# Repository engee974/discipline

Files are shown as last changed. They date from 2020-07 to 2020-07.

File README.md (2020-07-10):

# DISCIPLINE V2

**65% keyboard assembled with only through hole components, including usb type-c**

**[LICENSE](LICENSE)**

Discipline V2 is licensed under the [Creative Commons Attribution-NonCommercial 4.0 International License](https://creativecommons.org/licenses/by-nc/4.0/). 

This PCB design may be freely reproduced, modified, and manufactured for **PERSONAL USE ONLY** and may not be reproduced in physical form for public sale outside of [CFTKB.com](https://www.cftkb.com). 

If you have built upon this work and have changed the design in a significant way, the non-commercial clause can be waived. If you have developed your own design using files in this repository and would like to sell it, please contact me at bryan@cftkb.com. I fully support those looking to make new things and be creative and will more than likely approve and support your project.

**[BOM, Build Guide, and Flashing Information](./doc)**

**Kits available at [cftkb.com](https://www.cftkb.com)**

**[Optional High Profile Lasercut Acrylic Case](./case)**

discipline
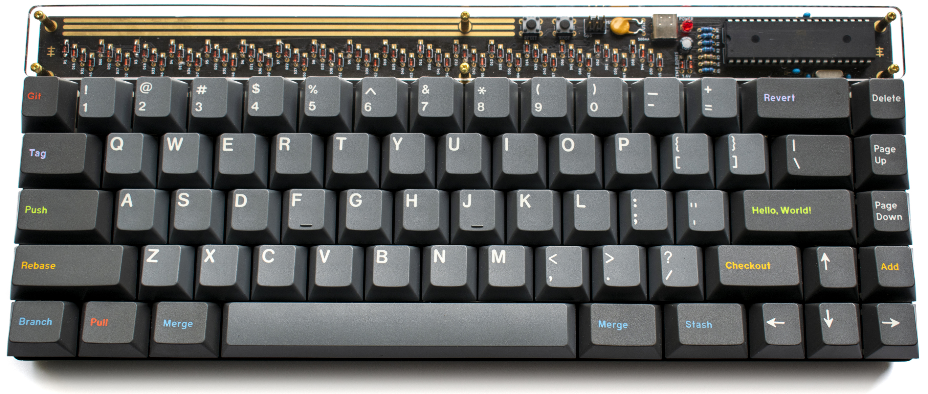
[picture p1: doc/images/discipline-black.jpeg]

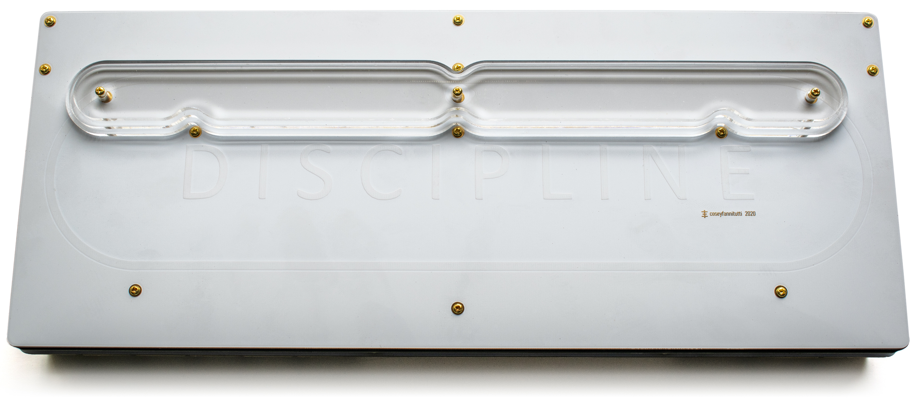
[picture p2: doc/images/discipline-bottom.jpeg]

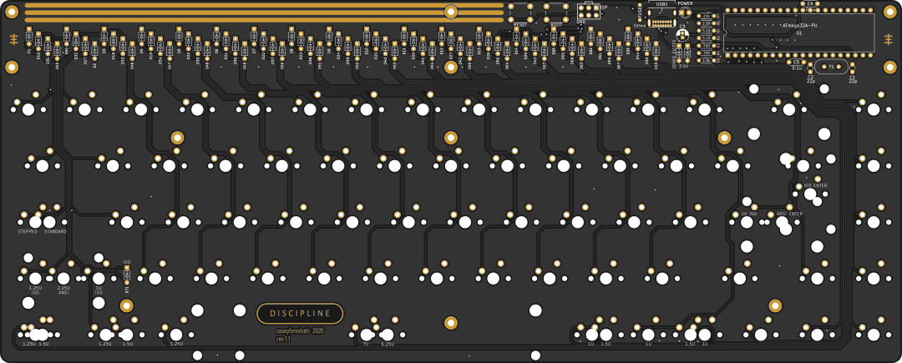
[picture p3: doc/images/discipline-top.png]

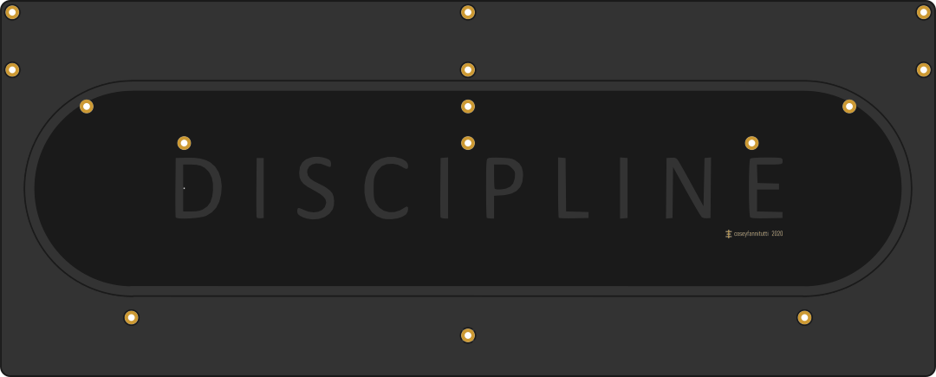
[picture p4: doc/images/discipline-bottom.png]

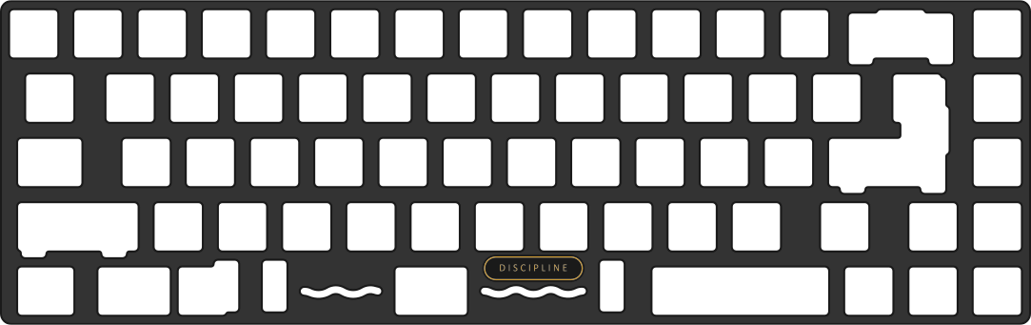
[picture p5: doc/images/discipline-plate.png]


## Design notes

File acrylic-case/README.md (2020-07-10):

# Lasercut Acrylic Case with POM Plate

***This is case is OPTIONAL and not required. The kit has everything you need for a fully functional keyboard.
This case uses a different plate and is NOT compatible with the plate included in the kit.
If you have already soldered switches, you will need to desolder them and swap the plate.***

***I recommend using [Ponoko](https://www.ponoko.com) to cut the pieces. They have all of the correct/required thicknesses and materials in stock and have the best pricing that I have found for multiple one-off parts. Use clear acrylic for the full range of thickness options and Delrin (POM) for the plate. For proper fit please ensure you use the correct dimensions and material thicknesses noted below. Other colors may be used, but of the colors may have limited thickness options, so you may have to narrow material results by thickness to see which colors are available for that size.***

***Ponoko's automatic size detection when uploading is not flawless, so be sure to manually enter the dimensions below.***

## Part Dimensions/Thickness (Top to Bottom)
1. discipline-top-1.dxf - 320.9 x 138.8 mm - ***2mm thickness CLEAR ACRYLIC***
2. discipline-top-2.dxf ***x2 needed*** - 320.9 x 138.8 mm - ***3mm***
3. discipline-plate.dxf - 320.9 x 138.8 mm - ***1.5mm thickness DELRIN(POM)*** Can be black or white.
4. discipline-open-layer.dxf - 320.9 x 138.8 mm - ***4.5mm thickness***
5. discipline-closed-layer.dxf - 320.9 x 138.8 mm - ***3mm thickness***
6. discipline-bottom.dxf - 320.9 x 138.8 - ***3mm thickness*** Use matte (frosted) or colored acrylic if you don't want to clean up the flux on the bottom of your PCB.
7. discipline-foot-1.dxf - 276.5 x 28mm - ***3mm thickness***
8. discipline-foot-2.dxf - 272.5 x 24mm - ***3mm thickness***
9. discipline-foot-3.dxf - 268.5 x 20mm - ***3mm thickness***

## Screws and Standoffs
1. [30x m2x5mm screws](https://www.aliexpress.com/item/32870342767.html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,searchweb201602_7,searchweb201603_53)
2. [12x m2x14mm standoffs](https://www.aliexpress.com/item/32968906213.html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,searchweb201602_7,searchweb201603_53)
3. [3x m2x5mm standoffs](https://www.aliexpress.com/item/32968906213.html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,searchweb201602_7,searchweb201603_53)



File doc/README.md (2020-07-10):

# DISCIPLINE

discipline

[Build Guide](https://static1.squarespace.com/static/5c533d33348cd92b886e544d/t/5e9fbf9e58f1fb0b01f71a7c/1587527585202/DISCIPLINE+BUILD+GUIDE.pdf)

[VIA Configurator Guide (Easiest)](https://static1.squarespace.com/static/5c533d33348cd92b886e544d/t/5e9fd1d198a4166c9ccc5b68/1587532241535/DISCIPLINE+VIA+GUIDE.pdf)

[QMK Toolbox Flashing Guide (not needed if using VIA)](https://static1.squarespace.com/static/5c533d33348cd92b886e544d/t/5e9fd3311e3c4e5bc9f8eb21/1587532594225/DISCIPLINE+FLASHING+GUIDE.pdf)

[Command Line Flashing Guide (Advanced)](https://static1.squarespace.com/static/5c533d33348cd92b886e544d/t/5e9fd3567e131c476b0a4f7e/1587532631133/DISCIPLINE+FLASHING+GUIDE+-+COMMAND+LINE.pdf)

[Bootloader](./bootloader)

[BOM (Parts List)](https://octopart.com/bom-tool/W4rybyut)

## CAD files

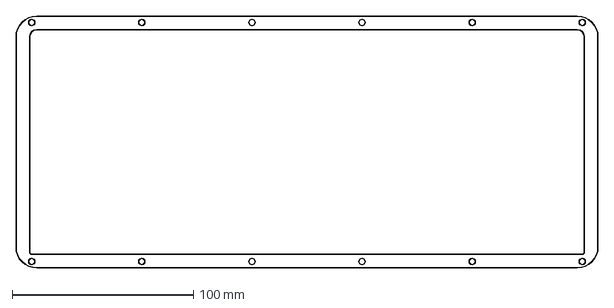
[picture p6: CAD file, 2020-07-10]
acrylic-case/discipline-top2.dxf
320.9 x 138.8 mm

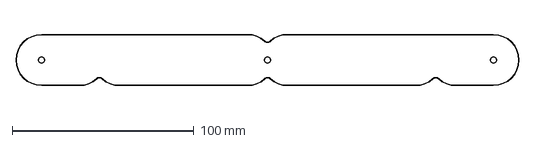
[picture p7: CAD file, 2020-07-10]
kit-acrylic/discipline-kitfoot-1.dxf
276.5 x 28.0 mm

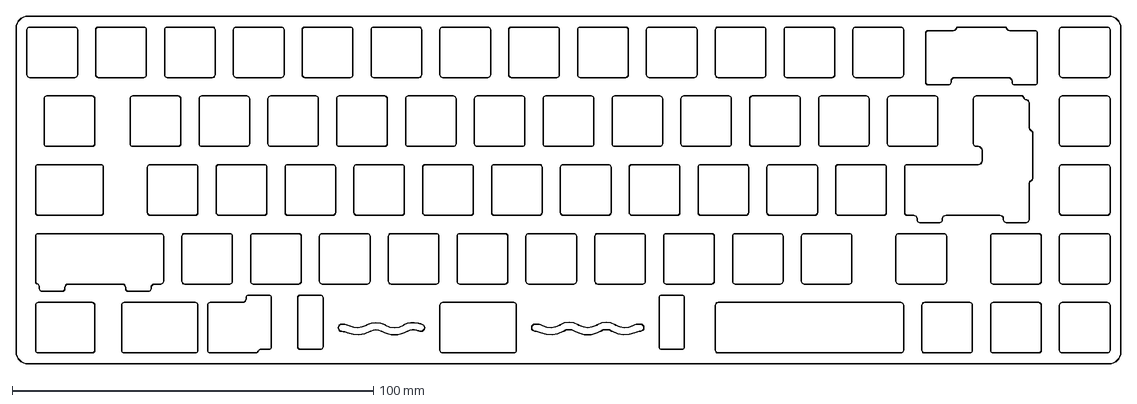
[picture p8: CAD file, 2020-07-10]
plate/discipline-plate-lasercutting.dxf
305.8 x 96.2 mm

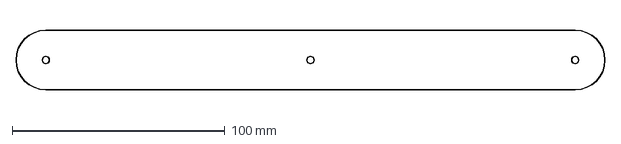
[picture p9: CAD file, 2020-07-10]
acrylic-case/discipline-foot-1.dxf
276.5 x 28.0 mm

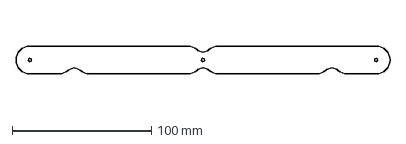
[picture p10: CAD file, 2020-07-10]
kit-acrylic/discipline-kitfoot-3.dxf
268.5 x 20.0 mm

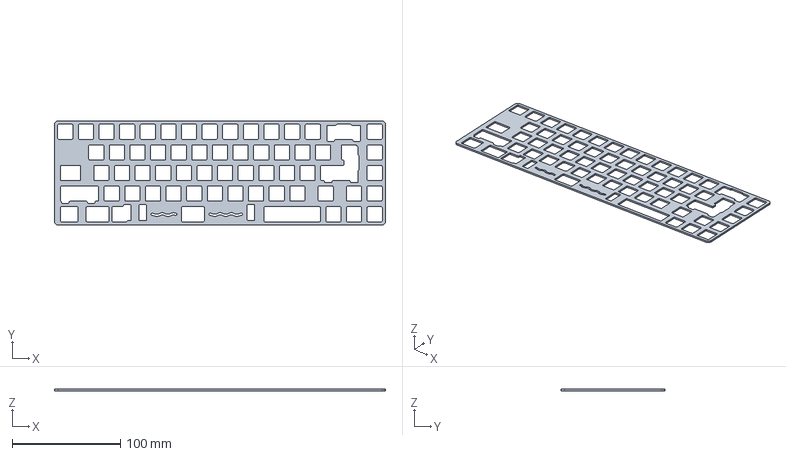
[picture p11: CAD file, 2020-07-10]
plate/discipline-pcb.step
305.8 x 96.2 x 1.60 mm

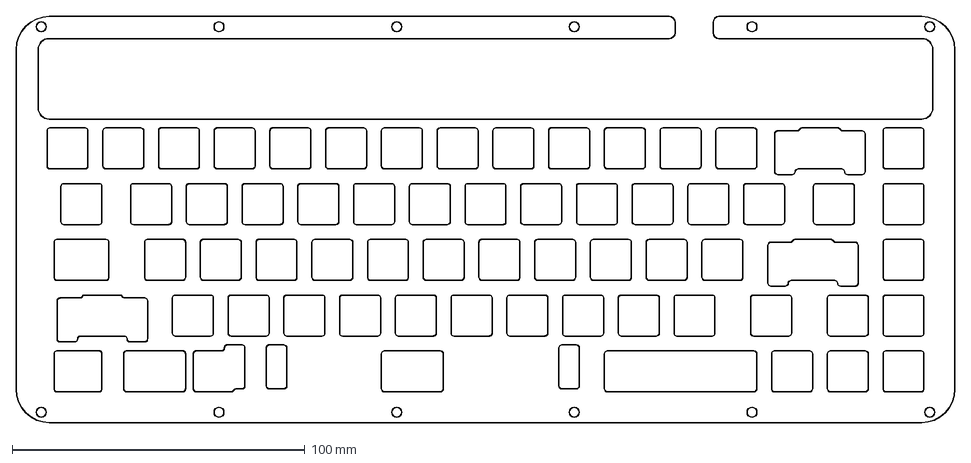
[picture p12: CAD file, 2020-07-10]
acrylic-case/discipline-plate.dxf
320.9 x 138.8 mm

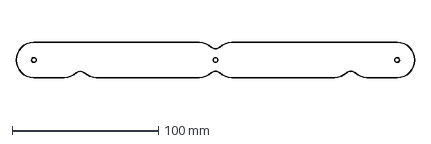
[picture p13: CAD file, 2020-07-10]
kit-acrylic/discipline-kitfoot-2.dxf
272.5 x 24.0 mm

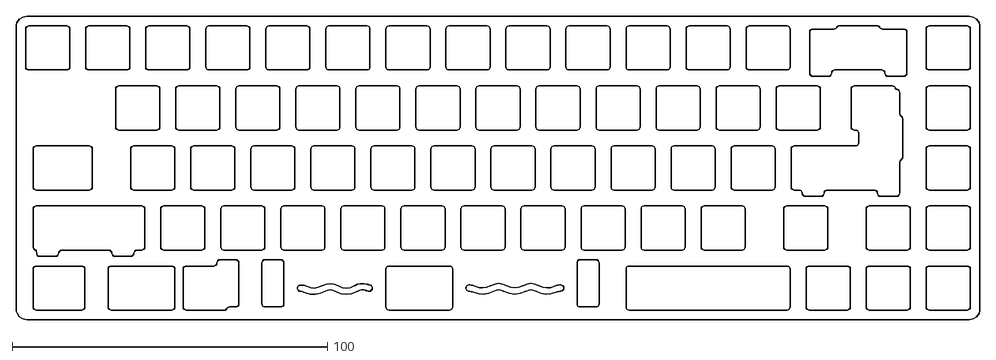
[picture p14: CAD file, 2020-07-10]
plate/discipline-plate-test.dxf
305.8 x 96.2

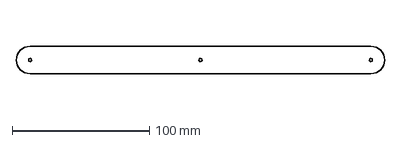
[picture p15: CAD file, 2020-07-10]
acrylic-case/discipline-foot-3.dxf
268.5 x 20.0 mm

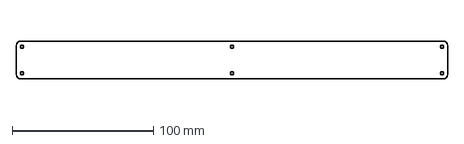
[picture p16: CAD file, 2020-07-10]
kit-acrylic/acrylic-guard.dxf
304.9 x 26.8 mm

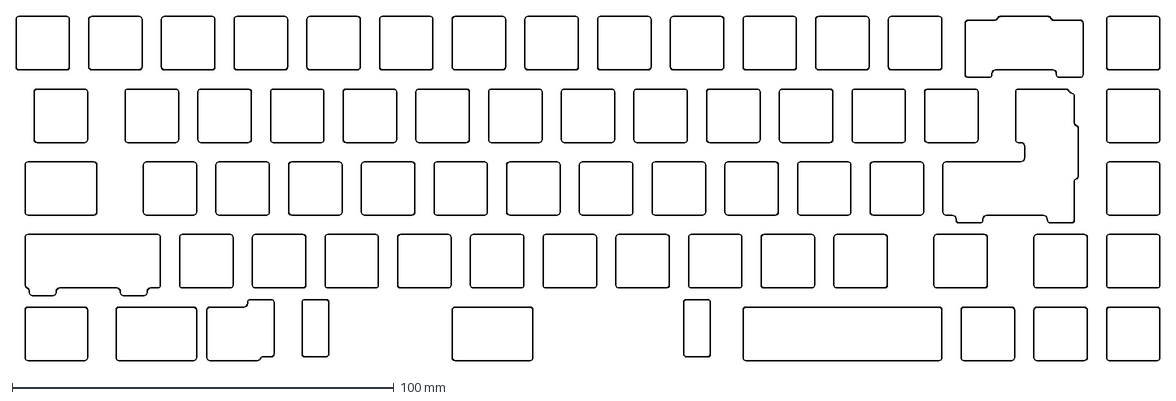
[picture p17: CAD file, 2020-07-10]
plate/discipline-plate-base.dxf
299.8 x 90.2 mm

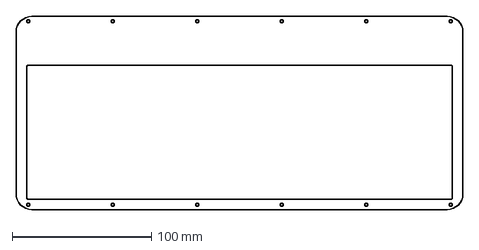
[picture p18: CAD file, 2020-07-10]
acrylic-case/discipline-top1.dxf
320.9 x 138.8 mm

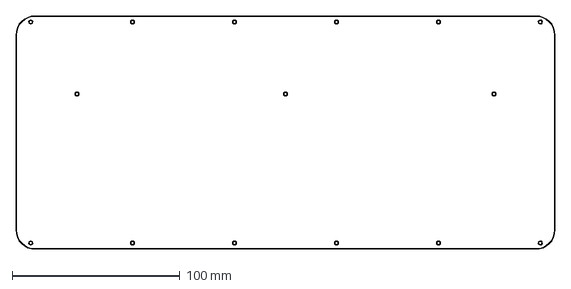
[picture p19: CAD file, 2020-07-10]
acrylic-case/discipline-bottom.dxf
320.9 x 138.8 mm

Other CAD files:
acrylic-case/discipline-open-layer.dxf
acrylic-case/discipline-closed-layer.dxf
acrylic-case/discipline-foot-2.dxf

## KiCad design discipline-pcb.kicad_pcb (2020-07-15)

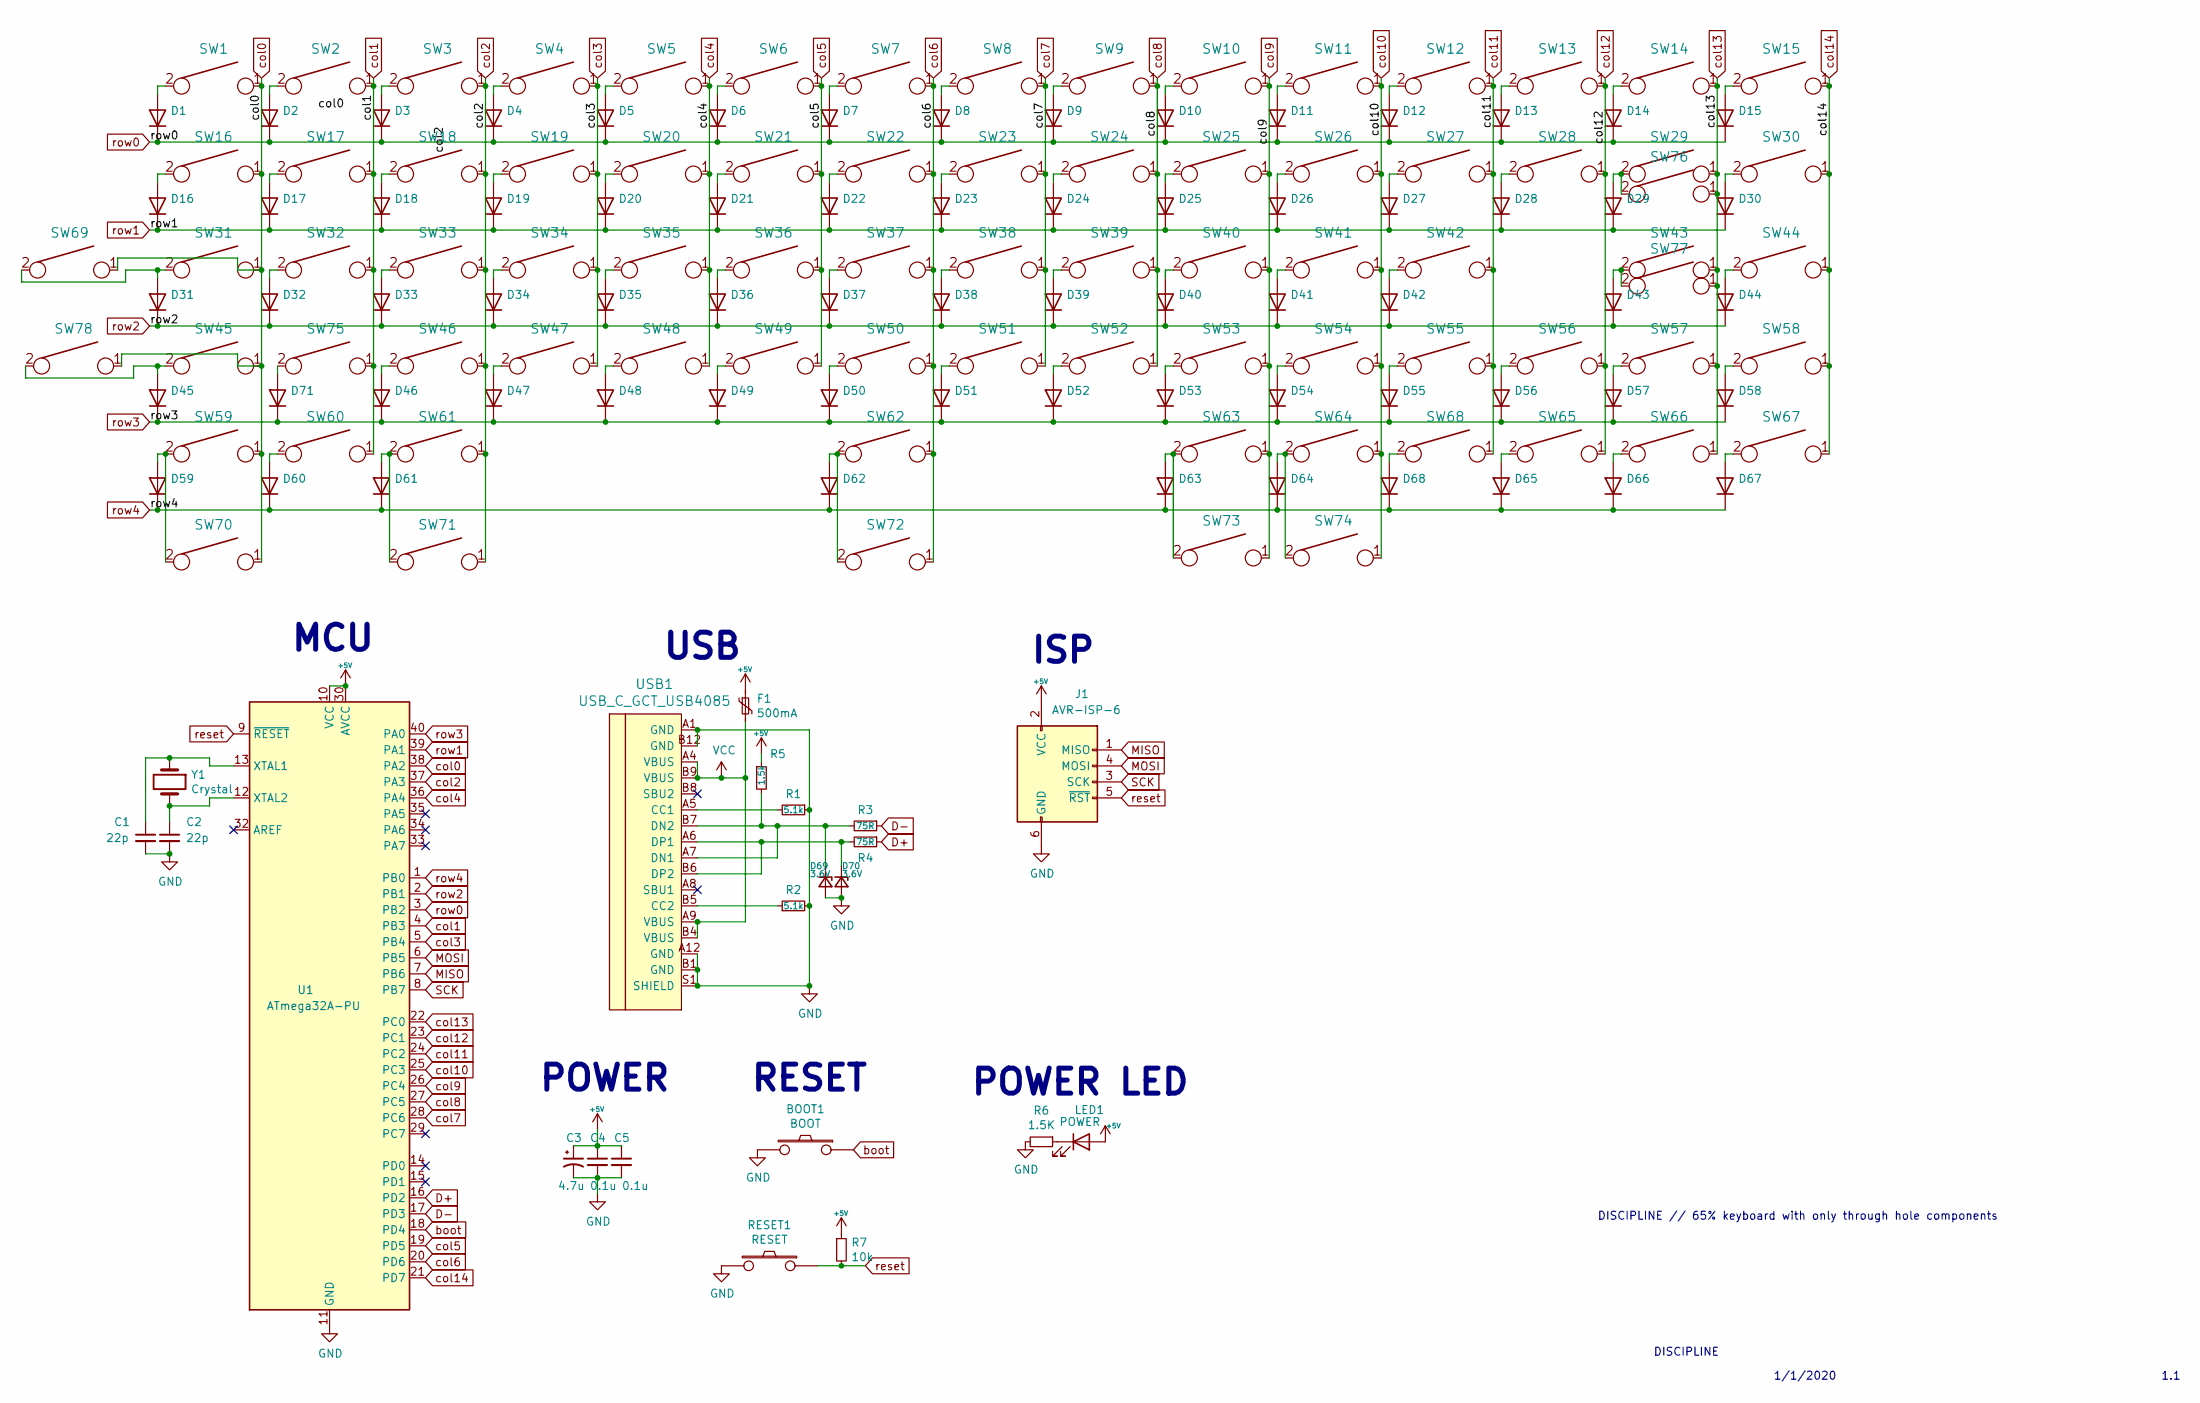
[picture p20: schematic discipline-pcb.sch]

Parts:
BOOT1: BOOT; SW_PUSH_6mm
C1, C2: 22p; C_Disc_D3.0mm_W1.6mm_P2.50mm
C3: 4.7u; CP_Radial_D4.0mm_P1.50mm
C4, C5: 0.1u; C_Disc_D4.3mm_W1.9mm_P5.00mm
D1, D2, D3, D4, D5, D6, D7, D8, D9, D10, D11, D12, D13, D14, D15, D16, D17, D18, D19, D20, D21, D22, D23, D24, D25, D26, D27, D28, D29, D30, D31, D32, D33, D34, D35, D36, D37, D38, D39, D40, D41, D42, D43, D44, D45, D46, D47, D48, D49, D50, D51, D52, D53, D54, D55, D56, D57, D58, D59, D60, D61, D62, D63, D64, D65, D66, D67, D68, D71: D_DO-35_SOD27_P5.08mm_Horizontal
D69, D70: 3.6V; D_DO-35_SOD27_P5.08mm_Horizontal
F1: 500mA; polyfuse_5.1mm
J1: AVR-ISP-6; AVR_ICSP_3x2
LED1: POWER; LED_D3.0mm
R1, R2: 5.1k; R_Axial_DIN0204_L3.6mm_D1.6mm_P5.08mm_Horizontal
R3, R4: 75R; R_Axial_DIN0204_L3.6mm_D1.6mm_P5.08mm_Horizontal
R5: 1.5k; R_Axial_DIN0204_L3.6mm_D1.6mm_P5.08mm_Horizontal
R6: 1.5K; R_Axial_DIN0204_L3.6mm_D1.6mm_P5.08mm_Horizontal
R7: 10k; R_Axial_DIN0204_L3.6mm_D1.6mm_P5.08mm_Horizontal
RESET1: RESET; SW_PUSH_6mm
SW1, SW2, SW3, SW4, SW5, SW6, SW7, SW8, SW9, SW10, SW11, SW12, SW13, SW15, SW17, SW18, SW19, SW20, SW21, SW22, SW23, SW24, SW25, SW26, SW27, SW28, SW30, SW32, SW33, SW34, SW35, SW36, SW37, SW38, SW39, SW40, SW41, SW42, SW44, SW46, SW47, SW48, SW49, SW50, SW51, SW52, SW53, SW54, SW55, SW57, SW58, SW62, SW65, SW66, SW67, SW68, SW72, SW75, SW77: KEYSW; SW_Cherry_MX1A_1.00u_PCB-NOSCREEN
SW14: KEYSW; SW_Cherry_MX1A_2.00u_PCBNOSCREEN
SW16, SW29, SW70, SW71, SW73, SW74: KEYSW; SW_Cherry_MX1A_1.50u_PCBNOSCREEN
SW31, SW56: KEYSW; SW_Cherry_MX1A_1.75u_PCBNOSCREEN
SW43, SW45: KEYSW; SW_Cherry_MX1A_2.25u_PCBNOSCREEN
SW59, SW60, SW61, SW63, SW64, SW69, SW78: KEYSW; SW_Cherry_MX1A_1.25u_PCBNOSCREEN
SW76: KEYSW; SW_Cherry_MX1A_ISOEnter_PCB_ReversedStabilizer
U1: ATmega32A-PU; DIP-40_W15.24mm
USB1: USB_C_GCT_USB4085
Y1: Crystal; Crystal_HC49-4H_Vertical

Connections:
+5V: C3.1, C4.1, C5.1, F1.1, J1.2 (VCC), LED1.2 (A), R5.1, R7.1, U1.10 (VCC), U1.30 (AVCC)
D+: R4.1, U1.16 (PD2)
D-: R3.1, U1.17 (PD3)
GND: BOOT1.1, C1.2, C2.2, C3.2, C4.2, C5.2, D69.2 (A), D70.2 (A), J1.6 (GND), R1.1, R2.2, R6.2, RESET1.1, U1.11 (GND), U1.31 (GND), USB1.A1 (GND), USB1.A12 (GND), USB1.B1 (GND), USB1.B12 (GND), USB1.S1 (SHIELD)
MISO: J1.1 (MISO), U1.7 (PB6)
MOSI: J1.4 (MOSI), U1.6 (PB5)
unnamed: C1.1, U1.13 (XTAL1), Y1.1
unnamed: C2.1, U1.12 (XTAL2), Y1.2
unnamed: D1.2 (A), SW1.2
unnamed: D2.2 (A), SW2.2
unnamed: D3.2 (A), SW3.2
unnamed: D4.2 (A), SW4.2
unnamed: D5.2 (A), SW5.2
unnamed: D6.2 (A), SW6.2
unnamed: D7.2 (A), SW7.2
unnamed: D8.2 (A), SW8.2
unnamed: D9.2 (A), SW9.2
unnamed: D10.2 (A), SW10.2
unnamed: D11.2 (A), SW11.2
unnamed: D12.2 (A), SW12.2
unnamed: D13.2 (A), SW13.2
unnamed: D14.2 (A), SW14.2
unnamed: D15.2 (A), SW15.2
unnamed: D16.2 (A), SW16.2
unnamed: D17.2 (A), SW17.2
unnamed: D18.2 (A), SW18.2
unnamed: D19.2 (A), SW19.2
unnamed: D20.2 (A), SW20.2
unnamed: D21.2 (A), SW21.2
unnamed: D22.2 (A), SW22.2
unnamed: D23.2 (A), SW23.2
unnamed: D24.2 (A), SW24.2
unnamed: D25.2 (A), SW25.2
unnamed: D26.2 (A), SW26.2
unnamed: D27.2 (A), SW27.2
unnamed: D28.2 (A), SW28.2
unnamed: D29.2 (A), SW29.2, SW76.2
unnamed: D30.2 (A), SW30.2
unnamed: D31.2 (A), SW31.2, SW69.2
unnamed: D32.2 (A), SW32.2
unnamed: D33.2 (A), SW33.2
unnamed: D34.2 (A), SW34.2
unnamed: D35.2 (A), SW35.2
unnamed: D36.2 (A), SW36.2
unnamed: D37.2 (A), SW37.2
unnamed: D38.2 (A), SW38.2
unnamed: D39.2 (A), SW39.2
unnamed: D40.2 (A), SW40.2
unnamed: D41.2 (A), SW41.2
unnamed: D42.2 (A), SW42.2
unnamed: D43.2 (A), SW43.2, SW77.2
unnamed: D44.2 (A), SW44.2
unnamed: D45.2 (A), SW45.2, SW78.2
unnamed: D46.2 (A), SW46.2
unnamed: D47.2 (A), SW47.2
unnamed: D48.2 (A), SW48.2
unnamed: D49.2 (A), SW49.2
unnamed: D50.2 (A), SW50.2
unnamed: D51.2 (A), SW51.2
unnamed: D52.2 (A), SW52.2
unnamed: D53.2 (A), SW53.2
unnamed: D54.2 (A), SW54.2
unnamed: D55.2 (A), SW55.2
unnamed: D56.2 (A), SW56.2
unnamed: D57.2 (A), SW57.2
unnamed: D58.2 (A), SW58.2
unnamed: D59.2 (A), SW59.2, SW70.2
unnamed: D60.2 (A), SW60.2
unnamed: D61.2 (A), SW61.2, SW71.2
unnamed: D62.2 (A), SW62.2, SW72.2
unnamed: D63.2 (A), SW63.2, SW73.2
unnamed: D64.2 (A), SW64.2, SW74.2
unnamed: D65.2 (A), SW65.2
unnamed: D66.2 (A), SW66.2
unnamed: D67.2 (A), SW67.2
unnamed: D68.2 (A), SW68.2
unnamed: D69.1 (K), R3.2, R5.2, USB1.A7 (DN1), USB1.B7 (DN2)
unnamed: D70.1 (K), R4.2, USB1.A6 (DP1), USB1.B6 (DP2)
unnamed: D71.2 (A), SW75.2
unnamed: LED1.1 (K), R6.1
unnamed: R1.2, USB1.A5 (CC1)
unnamed: R2.1, USB1.B5 (CC2)
SCK: J1.3 (SCK), U1.8 (PB7)
VCC: F1.2, USB1.A4 (VBUS), USB1.A9 (VBUS), USB1.B4 (VBUS), USB1.B9 (VBUS)
boot: BOOT1.2, U1.18 (PD4)
col0: SW1.1, SW16.1, SW31.1, SW45.1, SW59.1, SW69.1, SW70.1, SW78.1, U1.38 (PA2)
col1: SW2.1, SW17.1, SW32.1, SW60.1, SW75.1, U1.4 (PB3)
col2: SW3.1, SW18.1, SW33.1, SW46.1, SW61.1, SW71.1, U1.37 (PA3)
col3: SW4.1, SW19.1, SW34.1, SW47.1, U1.5 (PB4)
col4: SW5.1, SW20.1, SW35.1, SW48.1, U1.36 (PA4)
col5: SW6.1, SW21.1, SW36.1, SW49.1, U1.19 (PD5)
col6: SW7.1, SW22.1, SW37.1, SW50.1, SW62.1, SW72.1, U1.20 (PD6)
col7: SW8.1, SW23.1, SW38.1, SW51.1, U1.28 (PC6)
col8: SW9.1, SW24.1, SW39.1, SW52.1, U1.27 (PC5)
col9: SW10.1, SW25.1, SW40.1, SW53.1, SW63.1, SW73.1, U1.26 (PC4)
col10: SW11.1, SW26.1, SW41.1, SW54.1, SW64.1, SW74.1, U1.25 (PC3)
col11: SW12.1, SW27.1, SW42.1, SW55.1, SW68.1, U1.24 (PC2)
col12: SW13.1, SW28.1, SW56.1, SW65.1, U1.23 (PC1)
col13: SW14.1, SW29.1, SW43.1, SW57.1, SW66.1, SW76.1, SW77.1, U1.22 (PC0)
col14: SW15.1, SW30.1, SW44.1, SW58.1, SW67.1, U1.21 (PD7)
reset: J1.5 (~RST), R7.2, RESET1.2, U1.9 (~RESET)
row0: D1.1 (K), D2.1 (K), D3.1 (K), D4.1 (K), D5.1 (K), D6.1 (K), D7.1 (K), D8.1 (K), D9.1 (K), D10.1 (K), D11.1 (K), D12.1 (K), D13.1 (K), D14.1 (K), D15.1 (K), U1.3 (PB2)
row1: D16.1 (K), D17.1 (K), D18.1 (K), D19.1 (K), D20.1 (K), D21.1 (K), D22.1 (K), D23.1 (K), D24.1 (K), D25.1 (K), D26.1 (K), D27.1 (K), D28.1 (K), D29.1 (K), D30.1 (K), U1.39 (PA1)
row2: D31.1 (K), D32.1 (K), D33.1 (K), D34.1 (K), D35.1 (K), D36.1 (K), D37.1 (K), D38.1 (K), D39.1 (K), D40.1 (K), D41.1 (K), D42.1 (K), D43.1 (K), D44.1 (K), U1.2 (PB1)
row3: D45.1 (K), D46.1 (K), D47.1 (K), D48.1 (K), D49.1 (K), D50.1 (K), D51.1 (K), D52.1 (K), D53.1 (K), D54.1 (K), D55.1 (K), D56.1 (K), D57.1 (K), D58.1 (K), D71.1 (K), U1.40 (PA0)
row4: D59.1 (K), D60.1 (K), D61.1 (K), D62.1 (K), D63.1 (K), D64.1 (K), D65.1 (K), D66.1 (K), D67.1 (K), D68.1 (K), U1.1 (PB0)

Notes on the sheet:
DISCIPLINE // 65% keyboard with only through hole components
1/1/2020
DISCIPLINE
1.1
MCU
USB
ISP
POWER
RESET
POWER LED

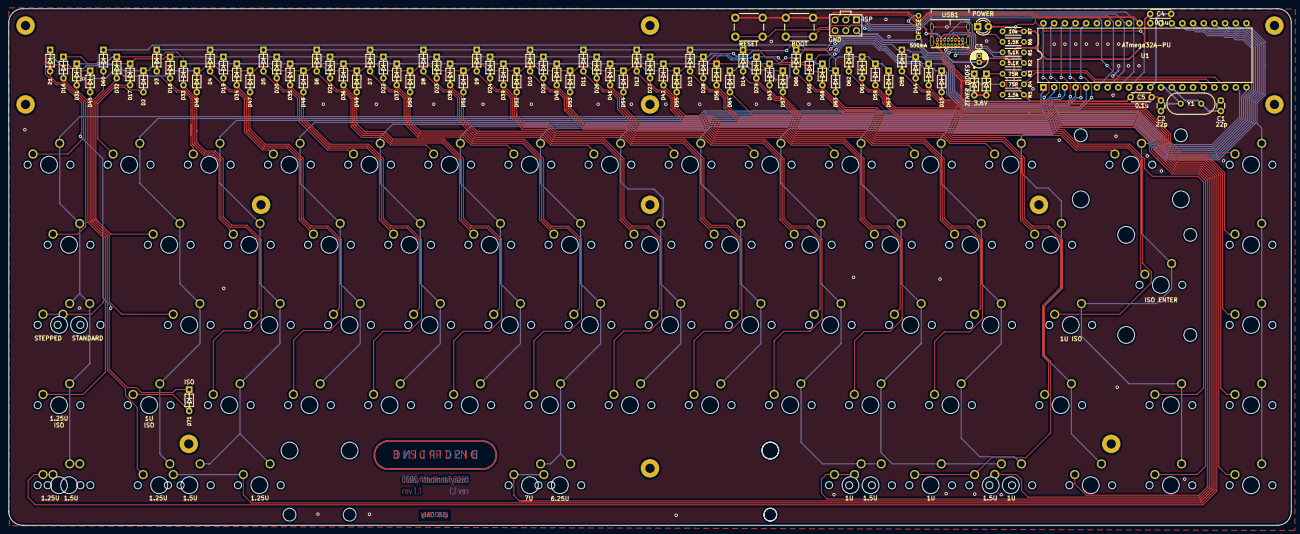
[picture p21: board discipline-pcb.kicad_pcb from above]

Board: 2 copper layers, 304.9 x 122.8 mm, 167 parts (0 on the bottom side), 106 nets.

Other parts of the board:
ST72: 7U; MX-7U-Stabilizer

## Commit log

2020-06-09 Start modify the PCB to match V2
    [discipline-pcb.kicad_pcb, discipline-pcb.sch]
2020-07-09 ISO Only Remove all keyswitch for ANSI layout from the PCB (schematic not modified)
    [discipline-pcb.kicad_pcb, discipline-pcb.sch]
2020-07-15 Modify all PCB to match the ISO Only layout
    [discipline-pcb-B_Cu.gbl, discipline-pcb-B_Mask.gbs, discipline-pcb-B_SilkS.gbo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]
